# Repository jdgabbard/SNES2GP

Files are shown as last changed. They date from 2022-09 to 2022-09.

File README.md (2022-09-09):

# SNES2GP
A DIY adapter for using SNES controllers on vintage IBM PC Compatibles.

The SNES-2-GP was created for the exact purpose of bringing a good controller to the Vintage PC community. The truth is, I was playing Duke Nukem one day and thought,”This would be so much fun if I had a controller to play it with.” And then it hit me, I could create one that worked through the Gameport. At first, I decided that I would just hack a reproduction NES controller to work with the Gameport. However, this project only sent me down the rabbit hole of what would become one of the best projects I have completed yet.

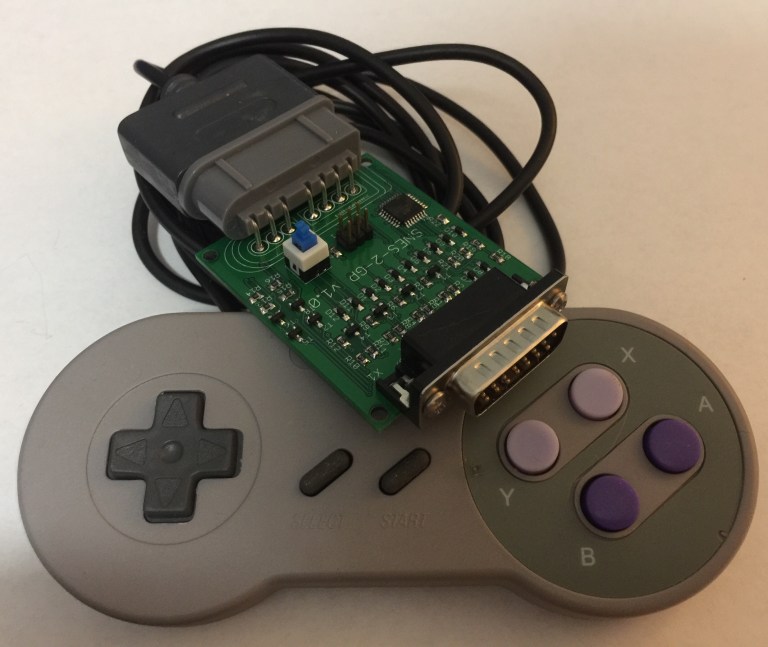
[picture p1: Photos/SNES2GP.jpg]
SNES2GP


Features include:<br><br>
-Two Working modes, determined by On/Off Switch.<br>
-Mode 1: Thrustmaster Compatible Mode.<br>
-Mode 2: 4-Axis Mode.<br>
-Two Primary Slots<br><br>

Disadvantages:<br><br>
-Appears to suffer from speed problems in some older DOS games. This causes the gamepad to not register movements in some cases.<br><br>

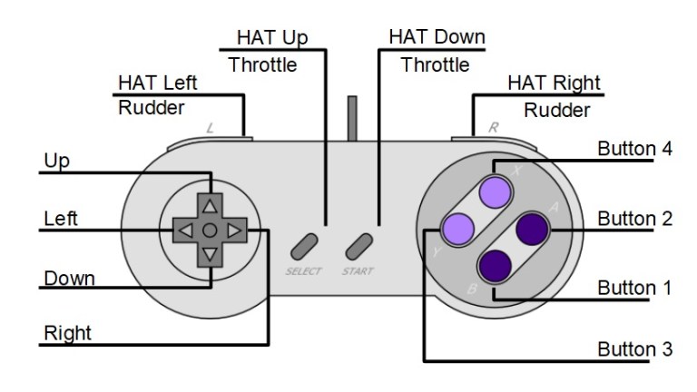
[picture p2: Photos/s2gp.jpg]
CONTROLS


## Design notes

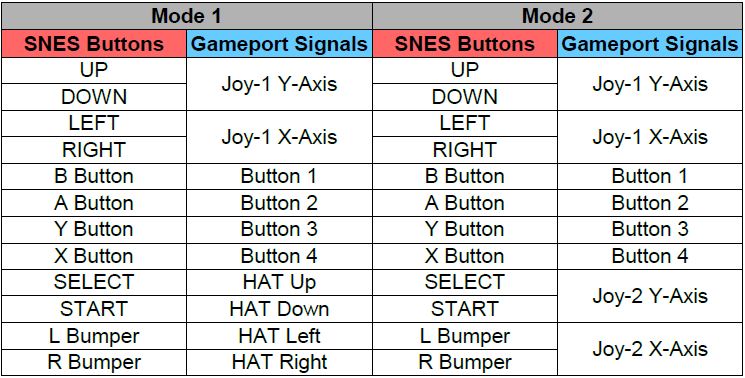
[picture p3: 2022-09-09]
Photos/Mapping.jpg

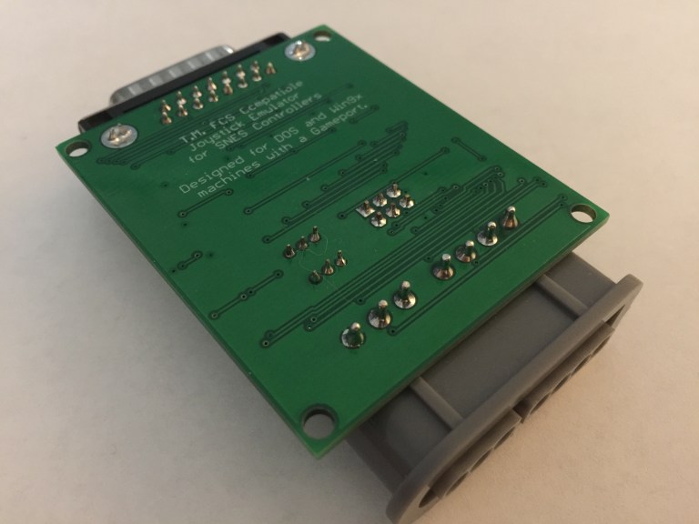
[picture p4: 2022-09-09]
Photos/SNES2GP3.jpg

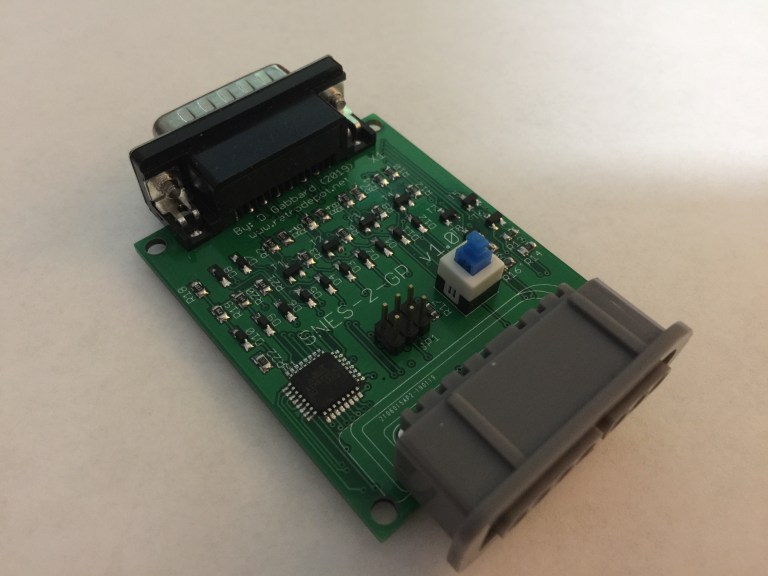
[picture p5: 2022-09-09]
Photos/SNES2GP2.jpg

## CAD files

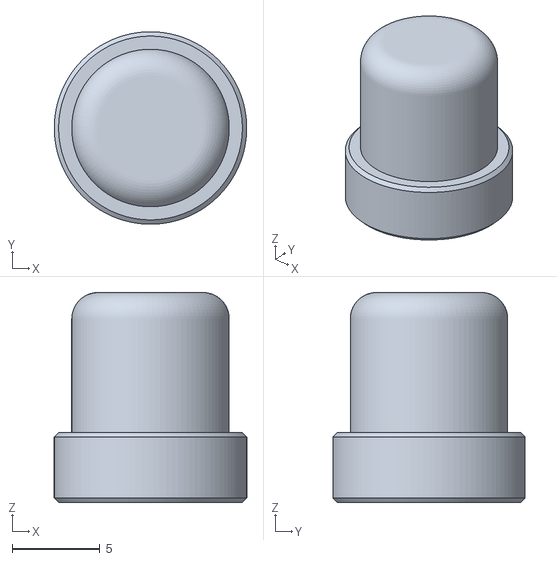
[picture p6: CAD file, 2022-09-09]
Case/V2_button.stl
11.0 x 11.0 x 12.0

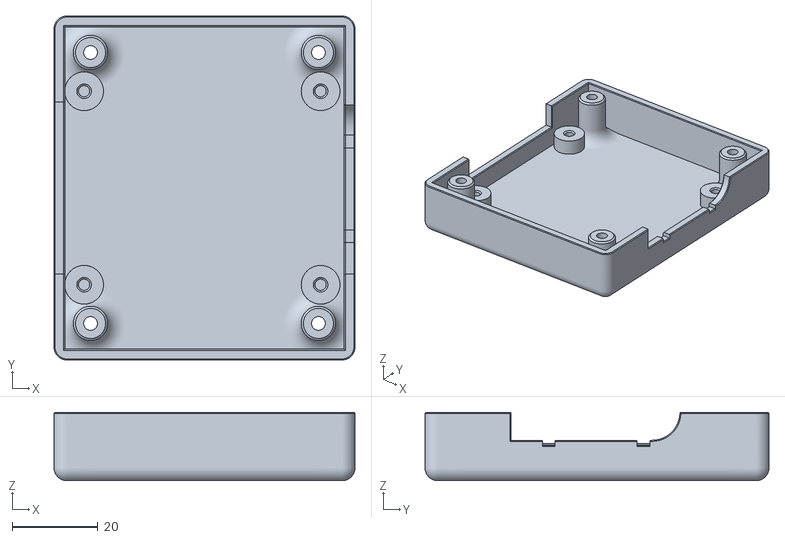
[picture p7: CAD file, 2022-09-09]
Case/V2_bottom.stl
70.0 x 80.0 x 15.9

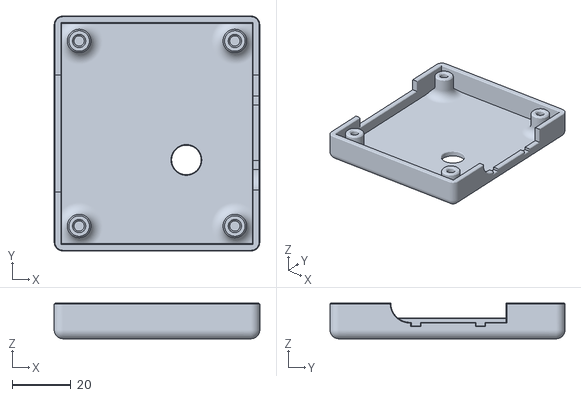
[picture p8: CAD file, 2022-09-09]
Case/V2_top.stl
70.0 x 80.0 x 12.1

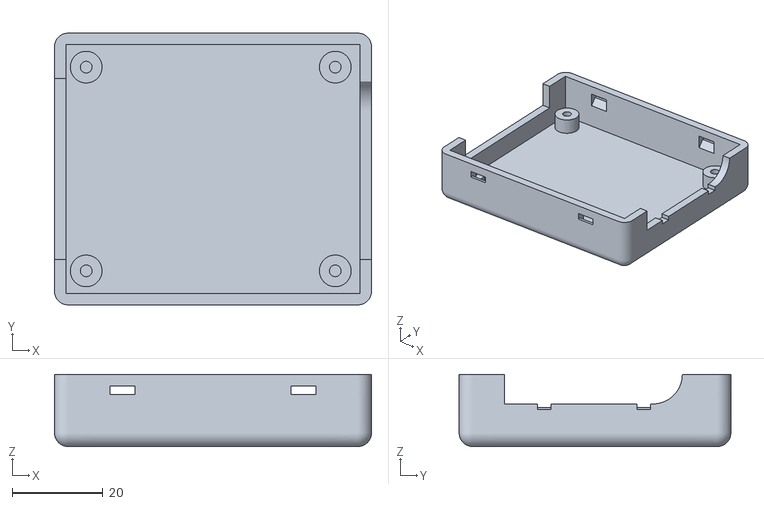
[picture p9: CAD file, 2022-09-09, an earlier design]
Case/V1_bottom.stl
70.0 x 60.0 x 15.9

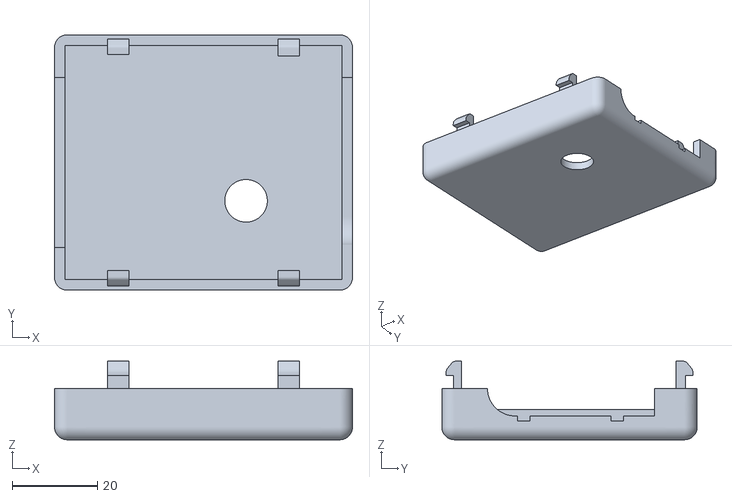
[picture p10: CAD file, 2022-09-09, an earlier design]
Case/V1_top.stl
70.0 x 60.0 x 18.4

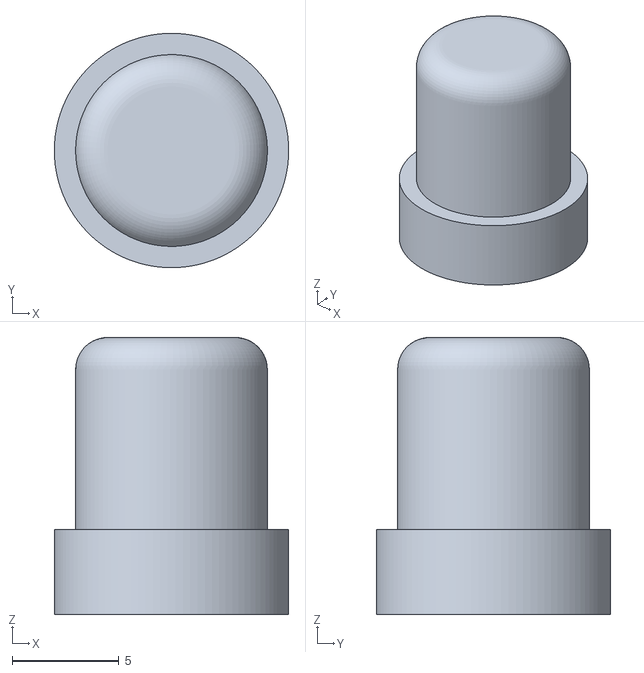
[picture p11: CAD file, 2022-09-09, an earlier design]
Case/V1_button.stl
11.0 x 11.0 x 13.0

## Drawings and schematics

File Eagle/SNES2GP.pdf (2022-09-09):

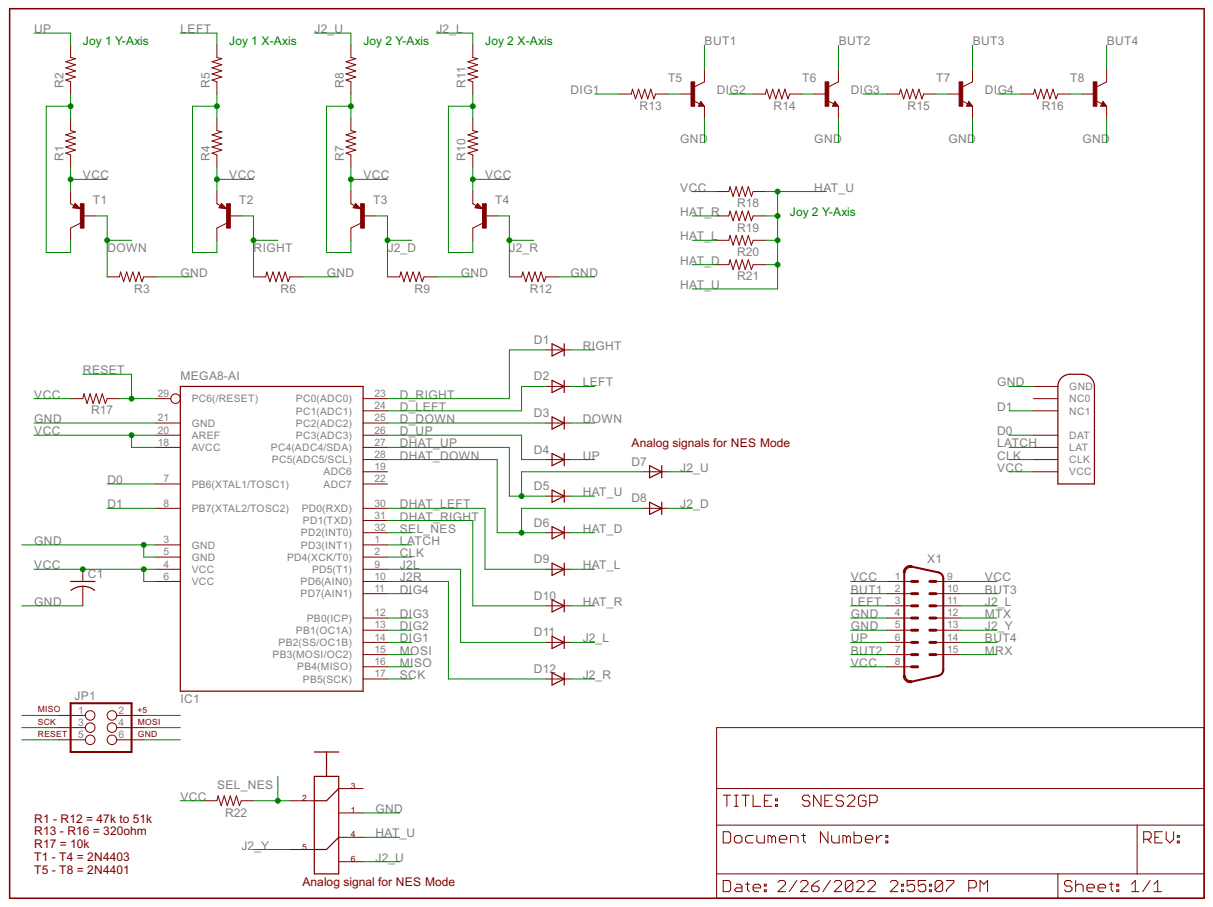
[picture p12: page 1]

Analog signals for NES Mode

Analog signal for NES Mode

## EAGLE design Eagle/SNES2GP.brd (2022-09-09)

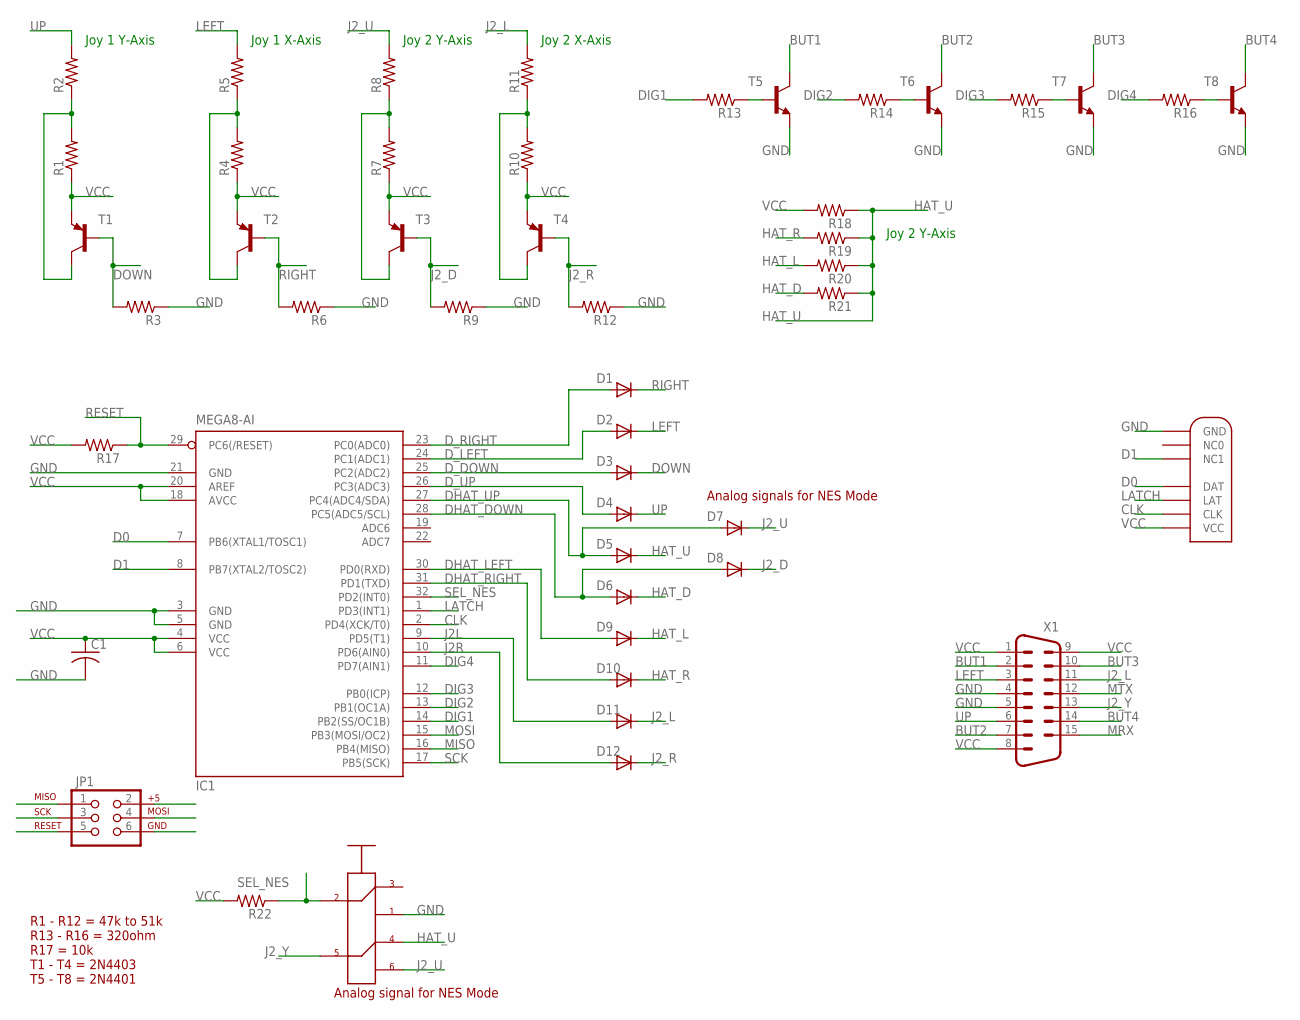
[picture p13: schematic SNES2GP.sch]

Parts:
C1: C-USC0805; C0805
D1, D2, D3, D4, D5, D6, D7, D8, D9, D10, D11, D12: DIODE-SOD323-W; SOD323-W
IC1: MEGA8-AI; TQFP32-08
JP1: AVR_SPI_PRG_6NS; 2X3-NS
R1, R2, R3, R4, R5, R6, R7, R8, R9, R10, R11, R12, R13, R14, R15, R16, R17, R18, R19, R20, R21, R22: R-US_M0805; M0805
T1, T2, T3, T4: MMBT3906; SOT23
T5, T6, T7, T8: MMBT3904; SOT23
U$1: 7X7_SW
U$3: SNES_GAMEPAD; SNESCONN
X1: M15HP

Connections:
BUT1: T5.3 (C), X1.2
BUT2: T6.3 (C), X1.7
BUT3: T7.3 (C), X1.10
BUT4: T8.3 (C), X1.14
CLK: IC1.2 (PD4(XCK/T0)), U$3.CLOCK (CLK)
D0: IC1.7 (PB6(XTAL1/TOSC1)), U$3.DATA (DAT)
D1: IC1.8 (PB7(XTAL2/TOSC2)), U$3.NC. (NC1)
DHAT_DOWN: D6.A, D8.A, IC1.28 (PC5(ADC5/SCL))
DHAT_LEFT: D9.A, IC1.30 (PD0(RXD))
DHAT_RIGHT: D10.A, IC1.31 (PD1(TXD))
DHAT_UP: D5.A, D7.A, IC1.27 (PC4(ADC4/SDA))
DIG1: IC1.14 (PB2(SS/OC1B)), R13.2
DIG2: IC1.13 (PB1(OC1A)), R14.2
DIG3: IC1.12 (PB0(ICP)), R15.2
DIG4: IC1.11 (PD7(AIN1)), R16.2
DOWN: D3.C, R3.2, T1.1 (B)
D_DOWN: D3.A, IC1.25 (PC2(ADC2))
D_LEFT: D2.A, IC1.24 (PC1(ADC1))
D_RIGHT: D1.A, IC1.23 (PC0(ADC0))
D_UP: D4.A, IC1.26 (PC3(ADC3))
GND: C1.2, IC1.3 (GND), IC1.5 (GND), IC1.21 (GND), JP1.6, R3.1, R6.1, R9.1, R12.1, T5.2 (E), T6.2 (E), T7.2 (E), T8.2 (E), U$1.P$1 (1), U$3.GND, X1.4, X1.5
HAT_D: D6.C, R21.2
HAT_L: D9.C, R20.2
HAT_R: D10.C, R19.2
HAT_U: D5.C, R18.1, R19.1, R20.1, R21.1, U$1.P$4 (4)
J2L: D11.A, IC1.9 (PD5(T1))
J2R: D12.A, IC1.10 (PD6(AIN0))
J2_D: D8.C, R9.2, T3.1 (B)
J2_L: D11.C, R11.2, X1.11
J2_R: D12.C, R12.2, T4.1 (B)
J2_U: D7.C, R8.2, U$1.P$6 (6)
J2_Y: U$1.P$5 (5), X1.13
LATCH: IC1.1 (PD3(INT1)), U$3.LATCH (LAT)
LEFT: D2.C, R5.2, X1.3
MISO: IC1.16 (PB4(MISO)), JP1.1
MOSI: IC1.15 (PB3(MOSI/OC2)), JP1.4
MRX: X1.15
MTX: X1.12
unnamed: R13.1, T5.1 (B)
unnamed: R1.2, R2.1, T1.3 (C)
unnamed: R14.1, T6.1 (B)
unnamed: R4.2, R5.1, T2.3 (C)
unnamed: R15.1, T7.1 (B)
unnamed: R7.2, R8.1, T3.3 (C)
unnamed: R16.1, T8.1 (B)
unnamed: R10.2, R11.1, T4.3 (C)
RESET: IC1.29 (PC6(/RESET)), JP1.5, R17.1
RIGHT: D1.C, R6.2, T2.1 (B)
SCK: IC1.17 (PB5(SCK)), JP1.3
SEL_NES: IC1.32 (PD2(INT0)), R22.1, U$1.P$2 (2)
UP: D4.C, R2.2, X1.6
VCC: C1.1, IC1.4 (VCC), IC1.6 (VCC), IC1.18 (AVCC), IC1.20 (AREF), JP1.2, R1.1, R4.1, R7.1, R10.1, R17.2, R18.2, R22.2, T1.2 (E), T2.2 (E), T3.2 (E), T4.2 (E), U$3.5V (VCC), X1.1, X1.8, X1.9

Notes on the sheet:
Joy 1 Y-Axis
Joy 1 X-Axis
R1 - R12 = 47k to 51k R13 - R16 = 320ohm R17 = 10k T1 - T4 = 2N4403 T5 - T8 = 2N4401
Joy 2 Y-Axis
Analog signals for NES Mode
Analog signal for NES Mode
Joy 2 X-Axis

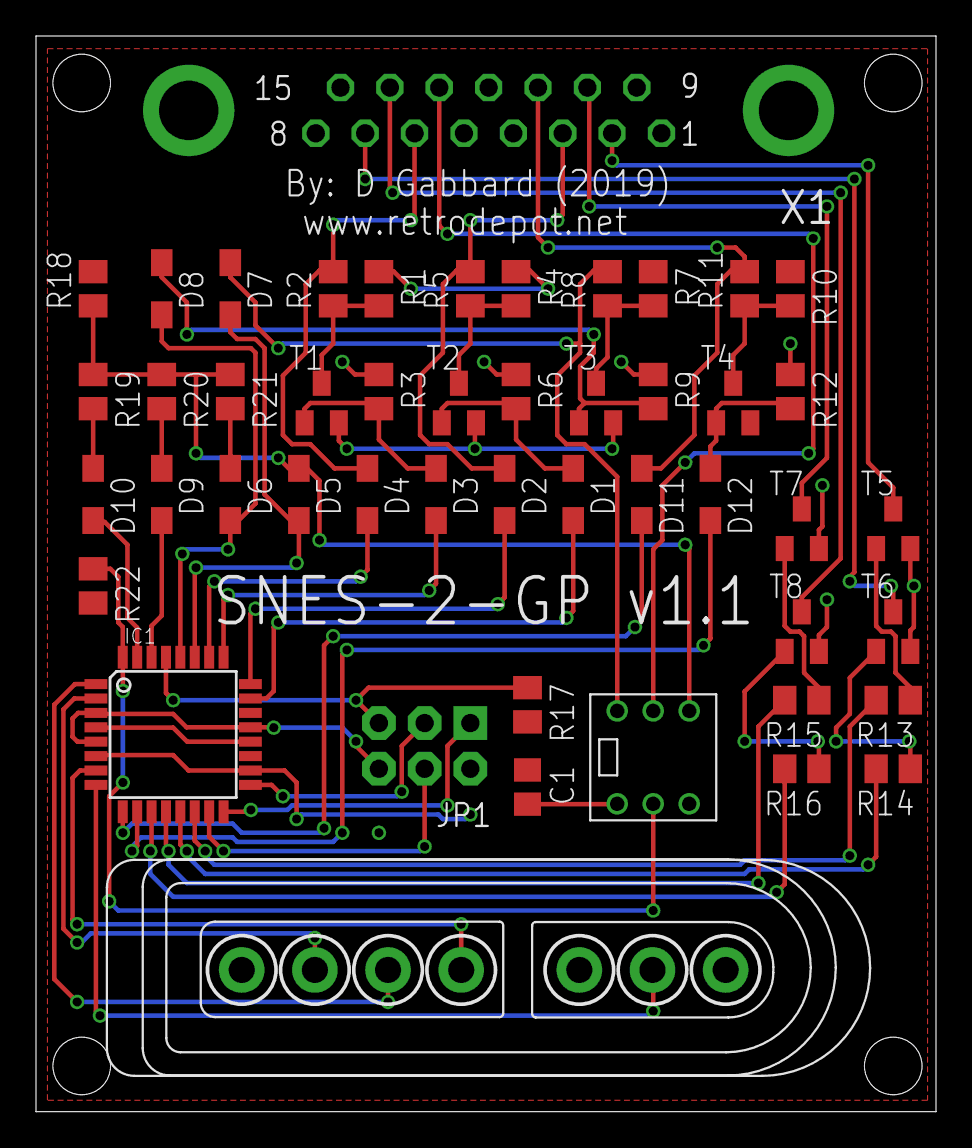
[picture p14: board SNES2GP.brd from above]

Board: 2 copper layers, 50.0 x 59.8 mm, 48 parts (0 on the bottom side), 50 nets.

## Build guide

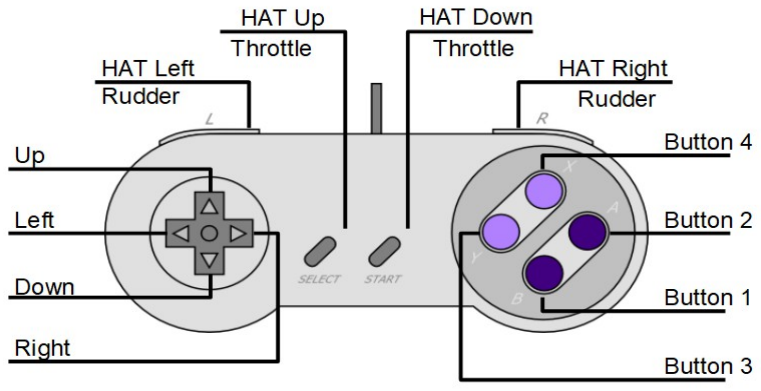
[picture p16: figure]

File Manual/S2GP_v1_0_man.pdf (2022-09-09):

# SNES-2-GP v1.0

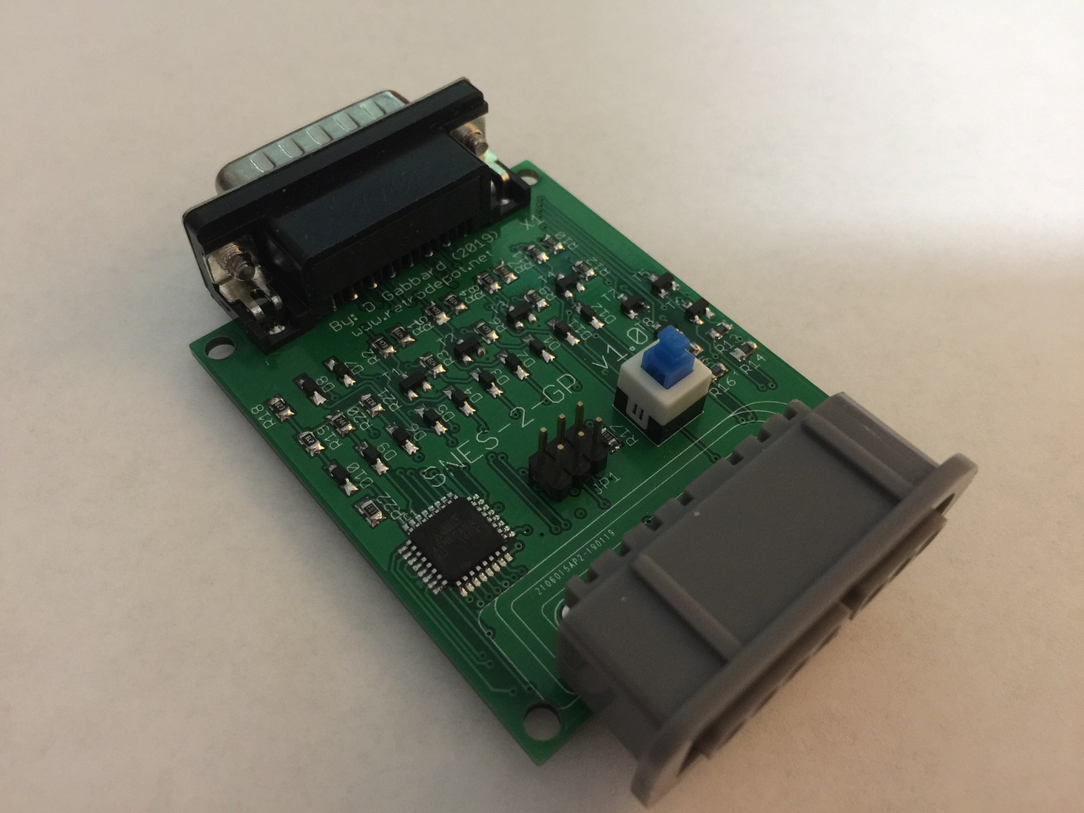
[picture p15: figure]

# USER MANUAL

### retrodepot.net

DESCRIPTION

The SNES-2-GP is a Gameport Interface Adapter allowing the use of SNES controllers on the PC. Unlike other adapter options, that are used through the parallel or serial ports, the SNES-2-GP doesn't require any special
drivers. | And game compatibility is no longer an issue: if it recognizes a
joystick, it will most likely work. | The SNES-2-GP emulates the Thrustmaster
FCS style joystick when used in 2-Axis mode. | The 4-Axis mode may be useful
when playing games that use the Throttle and/or Rudder.

INSTALLATION

Installation of the SNES-2-GP is simple:
1. Connect the SNES-2-GP through a male to female 1:1 D-Sub 15 (Low Density) cable (not included). Alternatively, the SNES-2-GP may be connected directly to the Gameport by replacing the screw receptacles with two 4-40 x 1/4 machine screws. However, this is not suggested, ” as it does not have enough holding strength to remain stably connected.
2. Plug in a SNES controller (not included).
3. Turn on the PC.
4. Calibrate the joystick in either the Windows environment, or your preferred game.
5. Enjoy your game with an awesome controller!

MODES OF OPERATION

The SNES-2-GP has two modes of operation: 2-Axis 4-Button with HAT mode, and 4-Axis 4-Button mode. These modes can be selected on the fly, and are
limited only by the software in which they are used with. | Selection of the
two modes is done by use of the locking switch on the board. | When up, the
board is set to 2-Axis mode. | And when down, the board is in 4-Axis mode.

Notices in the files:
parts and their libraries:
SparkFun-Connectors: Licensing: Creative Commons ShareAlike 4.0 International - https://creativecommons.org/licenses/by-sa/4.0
